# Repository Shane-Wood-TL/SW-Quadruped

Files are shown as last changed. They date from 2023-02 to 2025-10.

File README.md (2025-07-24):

# SW-Quadruped
Quadruped Robot similar to the Boston Dynamic's spot

# Version 9




Uses 12x DS32XX motors controlled by a set of PCA9685s <br>
<t> Planned upgrade to [these servos](https://github.com/Shane-Wood-TL/CAN_Servo/tree/main)<br>
Mircocontroller - ESP32-S3<br>
Gyro: BNO055 - Over CAN bus<br>
[Controller](https://github.com/Shane-Wood-TL/Universal-Robo-Controller)<br>
Lidar over ESP-NOW <br><br>

Power:
20V in from Dewalt battery (20V, 2A), <br>
20V into buck converter (20V - 6.4V),<br>
6.4V Powers servos, <br>
20V into buck converter (20V - 5V), <br>
5V powers ESP32-S3 as well as everything else <br>
I2C is based on 3V3 logic <br>

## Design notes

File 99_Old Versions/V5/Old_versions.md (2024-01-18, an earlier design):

# Version 7
Fixed the body issues of v6 with the use of carbon fiber tubes, similar to v6 otherwise.
PXL_20230803_034527840 PORTRAIT (1)

# Version 6


Similar to V5
The main goal is to reduce tolerance issues within V5 as well as make maintenance easier
Increase mobility range of legs which was reduced in the in/out direction due to the square nature of v5
Switch from a single PCB to 3, 1 main controller board with 2 servo driver boards, which communicate over a custom protocol that consists of I2C and some digital pins
Instead of using wires to connect these boards ethernet wires will be used instead, this is also the main way the controller will have access to other devices, it features 4 ethernet jacks
Given the digital pins that now go to the servo boards, a way to detect if the robot's leg is on the ground is also planned with the help of keyboard switches in the robot's foot

# Version 5
yeet

# Version 4


## Issues
Weak overall body
the way motors are connected to pieces leaves a lot of play
wires being consumed by the design
3d printed bearings not working well for hip joints

# Version 3


## Issues
an awful way for the motor's outputs to be connected

# Version 2


## Issues
Too big for the given motors
Lots of flex in the body
Too large and unstable to do anything

# Version 1


## Issues
Mirco Controller struggling to perform enough trig in a quick manner (could have been a motor issue)
Way too weak of motors (sg90s)
similar issues in stability and body strength as the version that follows

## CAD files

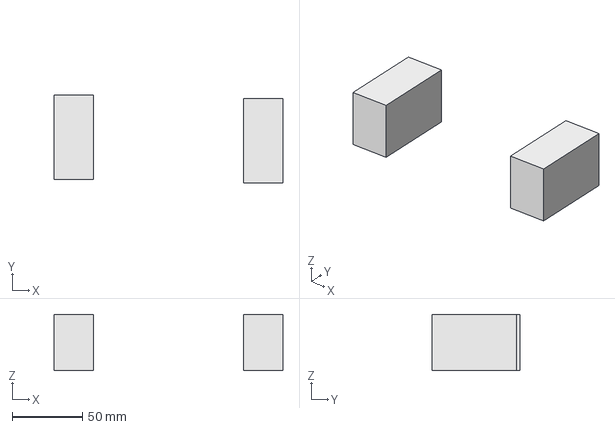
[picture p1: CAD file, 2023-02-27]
CAD/V5/assemblytest2.FCStd
163.3 x 62.5 x 40.3 mm

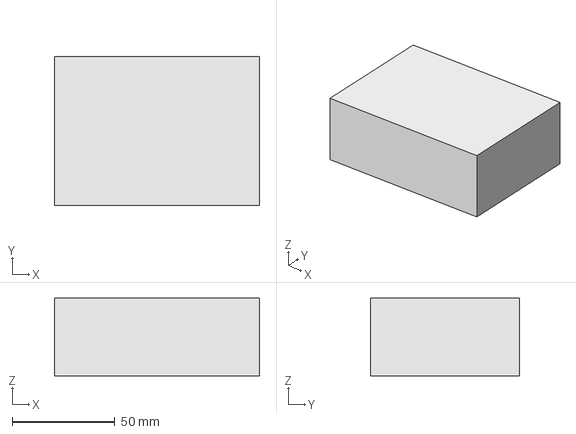
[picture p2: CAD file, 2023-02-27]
CAD/V5/placeholderparts/mainboard.FCStd
100.0 x 72.5 x 38.0 mm

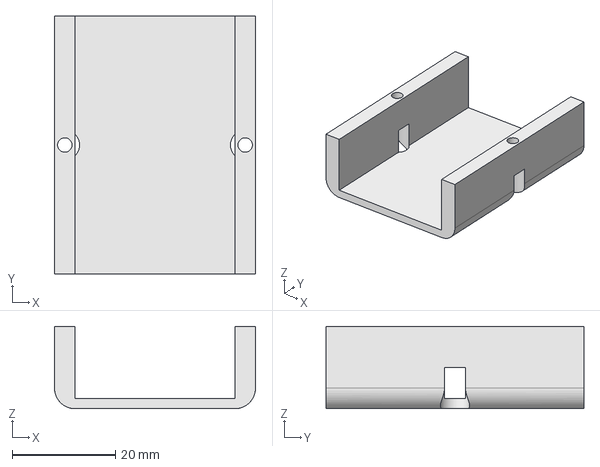
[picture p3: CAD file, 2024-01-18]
01_CAD/small_wire_Holder.FCStd
39.0 x 50.0 x 16.0 mm

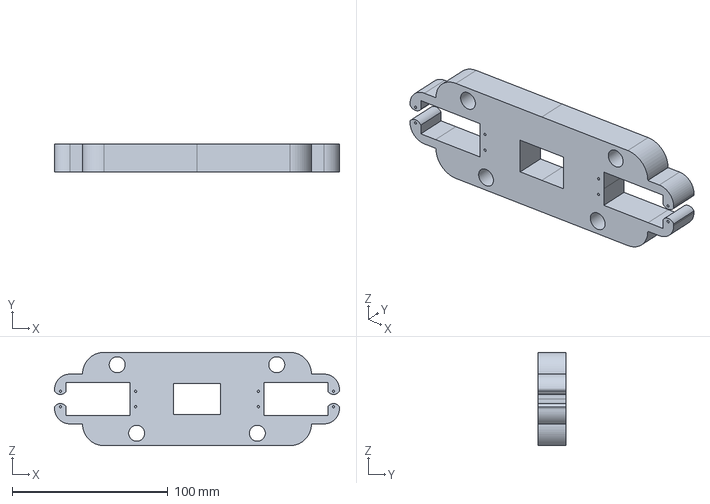
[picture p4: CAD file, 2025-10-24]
01_CAD/V10/Hip/INNER_PLATE.FCStd
183.0 x 18.0 x 60.0 mm

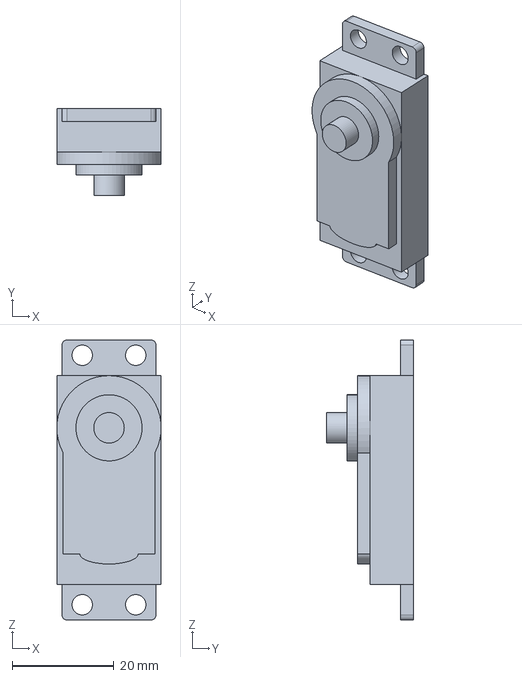
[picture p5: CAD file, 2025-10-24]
01_CAD/V10/Non_Printed_parts/MG996R_TOP.FCStd
20.5 x 17.0 x 55.0 mm

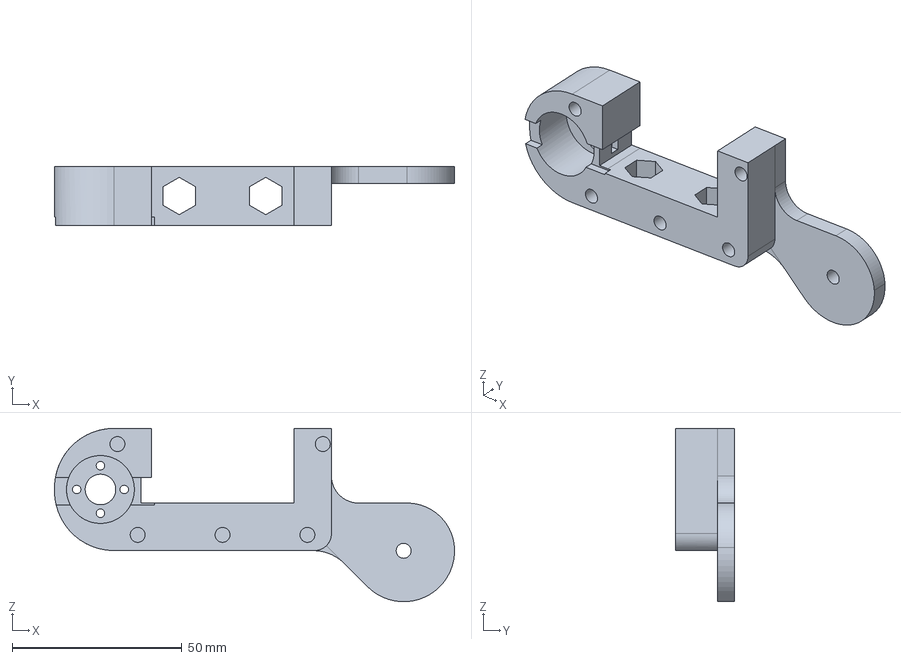
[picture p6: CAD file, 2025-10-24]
01_CAD/V10/Upper_Leg/UPPER_LEG_INNER.FCStd
117.8 x 17.5 x 51.0 mm

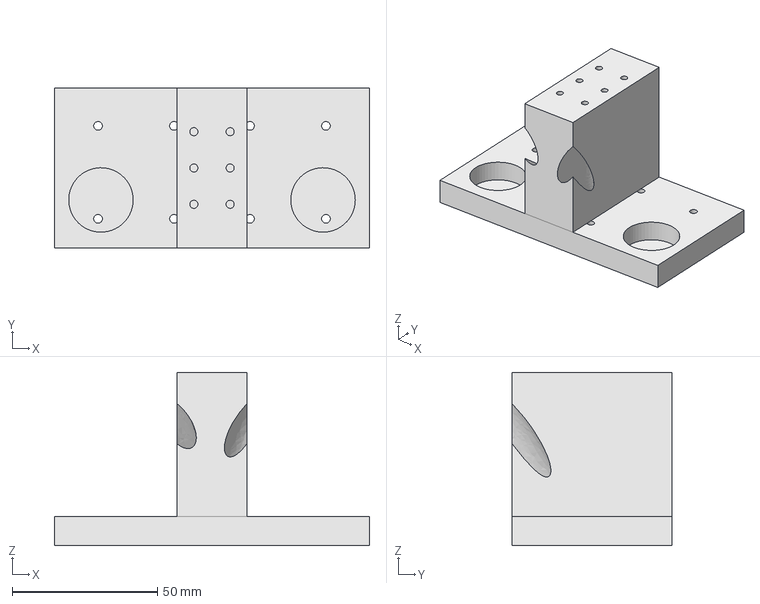
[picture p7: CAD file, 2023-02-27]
CAD/V5/Hip/BackSide/ButtBodyPlate.FCStd
108.5 x 55.0 x 59.8 mm

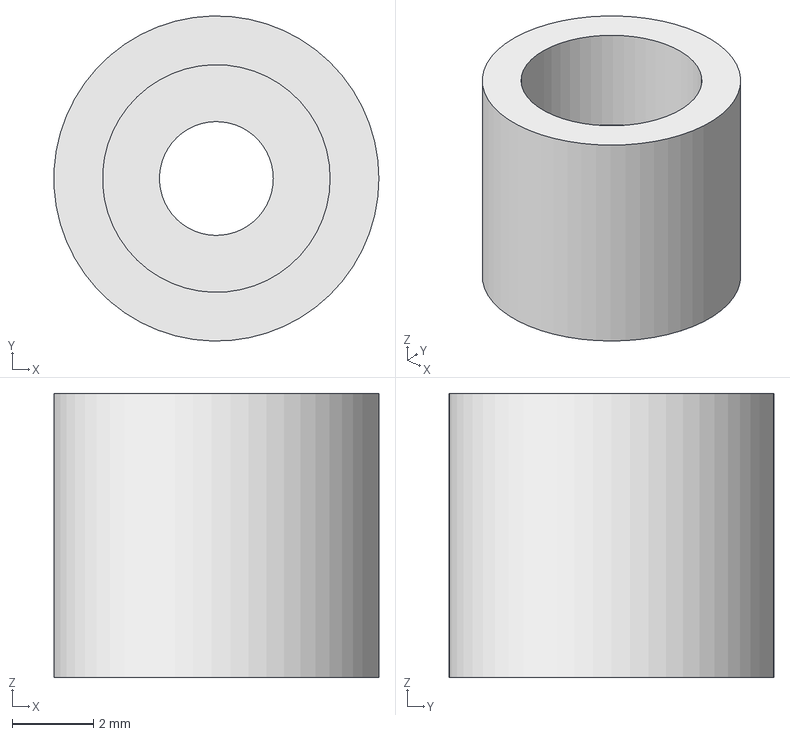
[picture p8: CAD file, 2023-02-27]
CAD/V5/Hip/fixed/bearingShaftFix.FCStd
7.99 x 8.00 x 7.00 mm

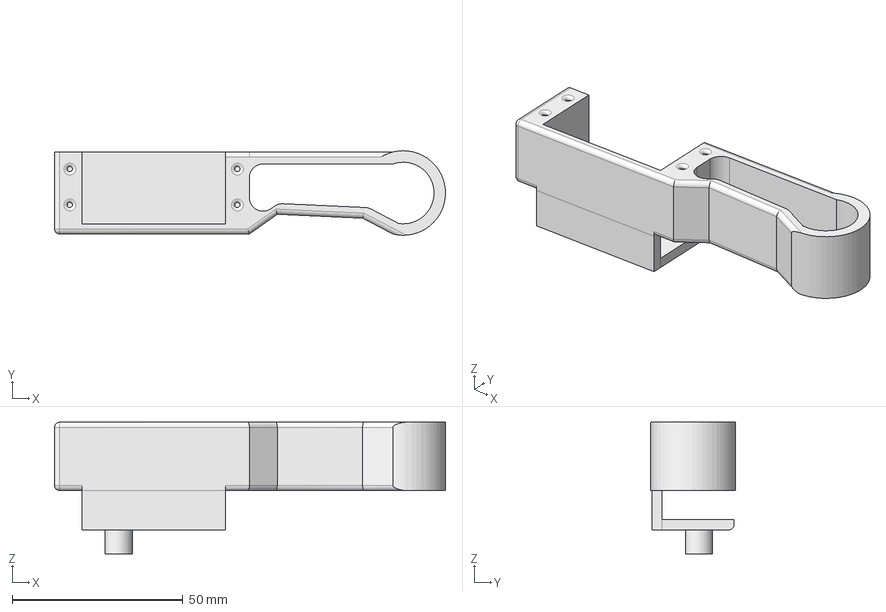
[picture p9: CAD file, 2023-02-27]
CAD/V5/LowerLeg/lowerLeg.FCStd
114.4 x 24.7 x 38.5 mm

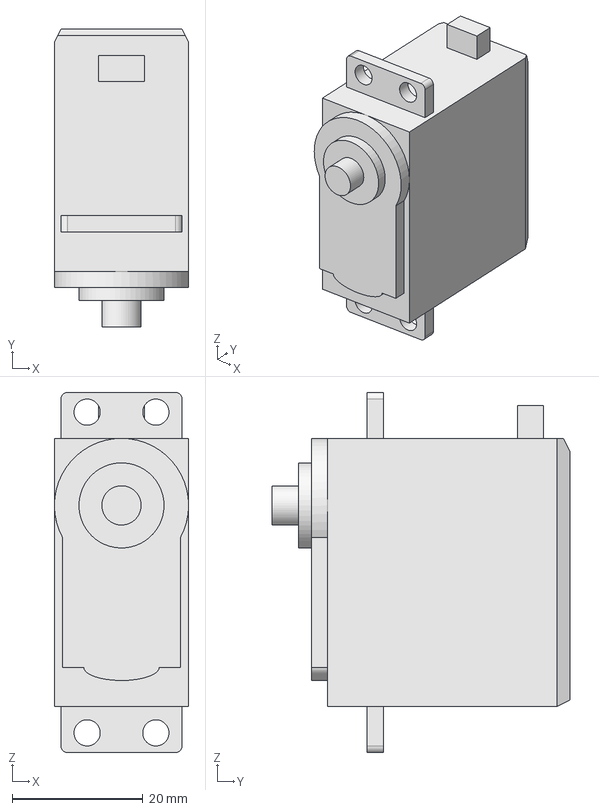
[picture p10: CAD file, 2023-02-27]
CAD/V5/MG996R.FCStd
20.5 x 45.5 x 55.0 mm

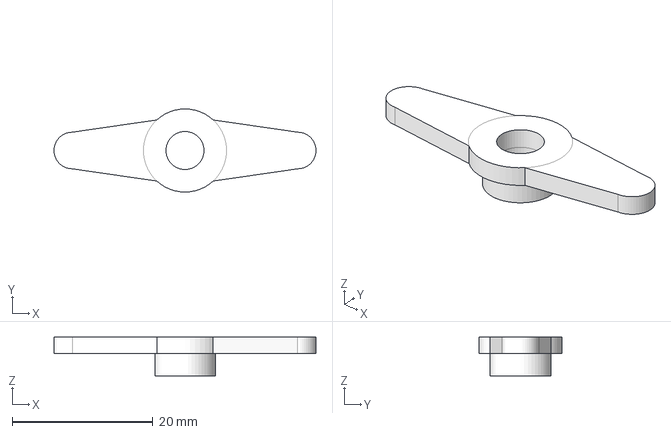
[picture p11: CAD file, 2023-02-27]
CAD/V5/NonPrintedParts/2servohorn.FCStd
37.2 x 11.8 x 5.50 mm

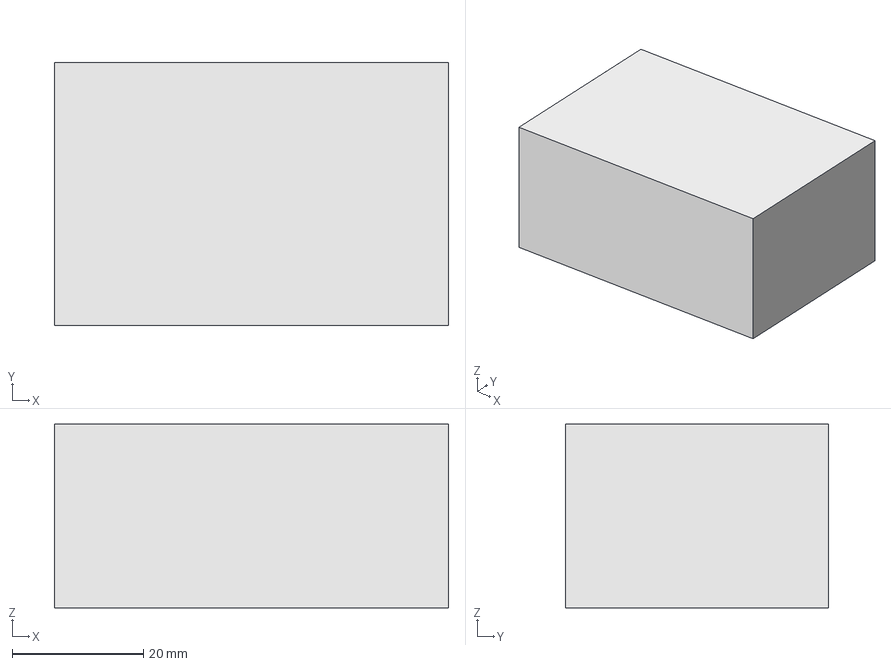
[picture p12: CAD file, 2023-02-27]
CAD/V5/placeholderparts/servoCapBoard.FCStd
60.0 x 40.0 x 28.0 mm

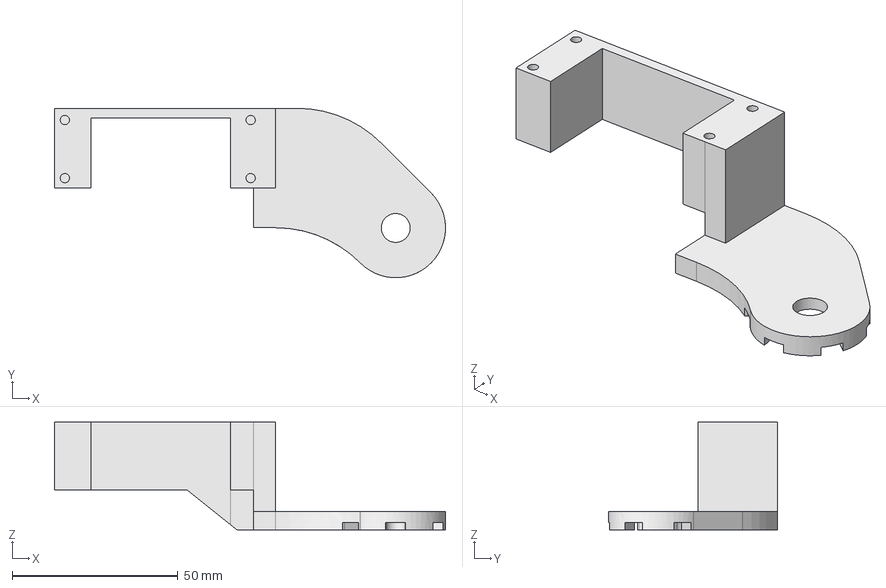
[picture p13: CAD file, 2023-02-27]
CAD/V5/Upper_leg/innerUppler leg.FCStd
117.8 x 51.1 x 32.5 mm

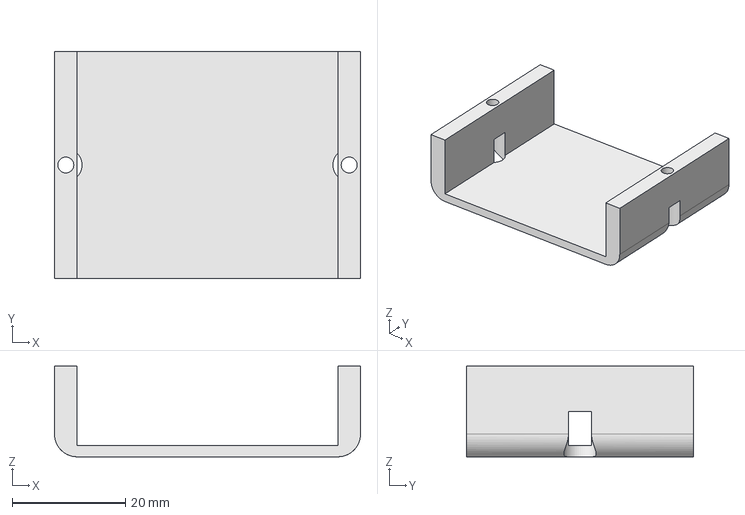
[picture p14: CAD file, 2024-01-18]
01_CAD/large_wire_Holder.FCStd
54.0 x 40.0 x 16.0 mm

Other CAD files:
CAD/V5/Body/bodyassembly.FCStd
01_CAD/V10/V10.FCStd
CAD/V5/Hip/FrontHipPlate.FCStd
01_CAD/V10/Hip/CAN_SERVO_PCB_HOLDER.FCStd
01_CAD/V10/Hip/KNEE_MOTOR_HOLDER.FCStd
01_CAD/V10/Hip/OUTER_PLATE.FCStd
01_CAD/V10/Non_Printed_parts/MG996R.FCStd
01_CAD/V10/Non_Printed_parts/circularServoHorn.FCStd
01_CAD/V10/Upper_Leg/UPPER_LEG_OUTER.FCStd
01_CAD/V7/Body/BatteryHolder.FCStd
01_CAD/V7/Body/Mainboard_Holder.FCStd
01_CAD/V7/Body/ServoDriver.FCStd
01_CAD/V7/Body/Servo_Driver_Holder.FCStd
01_CAD/V7/Body/batteryLid.FCStd
01_CAD/V7/Body/gyro holder.FCStd
01_CAD/V7/Body/lidar_Holder.FCStd
01_CAD/V7/Rod.FCStd
01_CAD/V7/assemv7.FCStd
01_CAD/V7/connecter.FCStd
01_CAD/V7/hip/innerplate.FCStd
01_CAD/V7/hip/plate.FCStd
01_CAD/V7/nonprintables/battery.FCStd
01_CAD/V8/Body/batholder.FCStd
01_CAD/V8/Body/buckandswitch.FCStd
01_CAD/V8/Body/kneeSupport.FCStd
01_CAD/V8/Body/lowandbuck.FCStd
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

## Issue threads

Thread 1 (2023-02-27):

Oscillation when robot attempts to fully level

Townlake101, 2023-02-27:
Needs some form of pid loop to establish a way to prevent the robot from changing its height too much during 1 move, especially if it is still essentially level.

Townlake101, 2023-04-18:
Also resolved with a PID loop + adding limits to the kinematic model to prevent motor damage

Closed 2023-04-18.

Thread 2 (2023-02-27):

Walking gate has not been tested with new gyro

Townlake101, 2023-02-27:

Townlake101, 2023-04-18:
PID added on gyro, oscillation is no longer present

Closed 2023-04-18.

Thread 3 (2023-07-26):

Motors do not move properly when xFB is positive (leg moving forward past the hip axis)

Townlake101, 2023-07-26:
Due to the different way that the kinematic model is calculated for this situation was well as some of the motors changing directions in between v5 to present this part of the code needs to be reworked

Townlake101, 2023-08-02:
Code for xFB (leg moving forward / backward) is working for backward movement and will base forward code upon the current design

Townlake101, 2023-08-11:
This issue has been resolved by adding a rule to handle positive xFB values differently in the kinematic model

Closed 2023-08-11.

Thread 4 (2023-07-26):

New cad needs to be uploaded

Shane-Wood-TL, 2023-07-26:
Cad in repository is currently based on v5

Townlake101, 2023-07-26:
Cad has been uploaded and moved, live files are still missing the leg model

Shane-Wood-TL, 2024-01-18:
V8 has been uploaded

Closed 2024-01-18.

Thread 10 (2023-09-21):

Robot Controller CAD + wiring diagram

Shane-Wood-TL, 2023-09-21:
CAD for robot controller needs to be added to the repository as well as how it is wired

Shane-Wood-TL, 2023-11-03:
PCB was made, so no wiring diagram, new cad does not exist yet, but it will be added once it is made

Shane-Wood-TL, 2024-01-18:
Added Under new repository, can be found here
https://github.com/Shane-Wood-TL/Universal-Robo-Controller

Closed 2024-01-18.

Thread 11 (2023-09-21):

Power for robot is unsatisfactory, at best

Shane-Wood-TL, 2023-09-21:
The current design of the bot uses a 65-watt USB C power bank and a USB PD breakout board to deliver 65W at 20V to the main buck converter. While this works it is far from ideal. The powerbank is heavy, a majority of the weight of the bot itself which is putting more strain on the motors. The USB PD board is not acceptable considering the amount of heat it outputs, leading to more energy loss.

Townlake101, 2023-09-21:
There is currently a plan to switch over to some form of power tool battery to stop using the USB PD board as it gets far hotter than a component in spec should. This switch would also add a fuse leading to some actual safety measures in the bot.

However, this switch is going to be costly so it will not happen until the limits of the 65W battery have been reached.

Shane-Wood-TL, 2023-11-03:
Battery conversion has been completed, BOM needs to be updated

Closed 2023-11-03.

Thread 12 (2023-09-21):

Using a SD card to save values

Townlake101, 2023-09-21:
Rather than having things like motor offsets hard-coded into the files allowing the user to set them via the controller and save them internally onto the robot would allow for a better user experience and might make the creation of custom moves easier

Shane-Wood-TL, 2023-11-03:
Rather than add a sd card, having some way to show the offset on the controller and then being able to add them in code is likely a better way to resolve this issue

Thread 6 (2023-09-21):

Ethernet is too bulky in design

Townlake101, 2023-09-21:
The ethernet jacks on the main controller make it impossible to use all 4 jacks as it will hit the gyro holder. Switching to a low profile connecter would resolve this

Townlake101, 2023-09-21:
New PCB version (not pushed yet) switches to generic 2x5 2.54 breadboard headers witch should resolve this issue

Shane-Wood-TL, 2023-11-03:
This had been fully resolved and tested with the current pcb

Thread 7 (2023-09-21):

Mainboard Issues

Shane-Wood-TL, 2023-09-21:
The mainboard is missing a good 3V3 volt source (taking power from ESP32 is not advisable) Next PCB should have a 3v3 volt regulator. Along with this, the I2C bus needs to be fully converted to 3V3 as the PCA9685's are still currently on a 5V setup which could damage the ESP32.

Along with this, a spot for the NRF2401 should be added to the PCB since it is the radio that is used.

Townlake101, 2023-09-21:
The new PCB version (not pushed yet) has a 3v3 regulator on board and a spot for the NRF2401 with a capacitor in place. It also switches the PCA9685s to 3v3

Shane-Wood-TL, 2023-11-03:
This issue has been fully resolved with the current pcb

Closed 2023-11-03.

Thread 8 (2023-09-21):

User control does not work as expected

Shane-Wood-TL, 2023-09-21:
Unsure of why this is, motors either do not move at all or they are moving in the wrong direction. Debugging this will take a bit, however, user control is vital to having non-human control in the future.

Shane-Wood-TL, 2024-01-18:
User control works as expected, it needs further tweaking, but it is functional

Closed 2024-01-18.

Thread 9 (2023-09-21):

Gyro + Controller

Townlake101, 2023-09-21:
Gyro does not appear to work with the controller even if enabled. Suspecting it is a issue with the PID controller as it might be getting to far away from 0 leading to unexpected results

Shane-Wood-TL, 2023-11-03:
Pid is still currently broken as well as writing angles to the legs when walking. The gyro is implemented properly in terms of the base kinematic model

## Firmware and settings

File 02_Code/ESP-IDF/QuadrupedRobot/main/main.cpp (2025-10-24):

#include "../include/hardware_setup/pinout.h"
#include "../include/hardware_setup/i2c_setup.h"
#include "../include/hardware_setup/motor_offsets.h"
#include "../include/wireless_setup/structures.h"
#include "../include/all_includes.h"
#include "../include/motion_system/structures.h"
#include "../include/motion_system/kinematics.h"
#include "../include/motion_system/ramp_leg.h"
#include "../include/motion_system/ramped_kinematics.h"
#include "../include/motion_system/robot_movement.h"

#include "../include/drivers/bno055.h"

#include <nvs_flash.h>
#include "espnow_ctrl.h"
#include "espnow_utils.h"

#include "led_strip.h"

#include "driver/adc.h"
//#include "driver/i2c_master.h"
void servo_driver(void *pv);
void send_data_task(void *pv);
void led_driver(void *pv);
void current_voltage_measurements_task(void *pv);
void gyroscope_task(void *pv);

void start_esp_now();
void start_I2C();
void start_TWAI();

static uint8_t robotMacAddress[6] = {0x34, 0x85, 0x18, 0xA5, 0x74, 0x48};
static uint8_t controller_mac_address[6] = {0x68,0xB6,0xB3,0x52,0xB1,0xAC};

controller_to_bot_payload controller_to_bot = {0};


enum mode_options_enum{STAND, IK, WALK, TURN, USER, MOTORSET};


SemaphoreHandle_t mode_mutex;
uint8_t mode =0;

SemaphoreHandle_t settings_mutex;
bool pid =false;
bool gyro = false;
bool motors_disabled = true;

SemaphoreHandle_t joystick_0_x_mutex;
int8_t joystick_0_x=0;

SemaphoreHandle_t joystick_0_y_mutex;
int8_t joystick_0_y=0;

SemaphoreHandle_t joystick_1_x_mutex;
int8_t joystick_1_x=0;

SemaphoreHandle_t joystick_1_y_mutex;
int8_t joystick_1_y=0;

SemaphoreHandle_t battery_voltage_mutex;
float battery_voltage=0;

SemaphoreHandle_t battery_current_mutex;
float battery_current=0;

SemaphoreHandle_t motor_current_mutex;
float motor_current=0;


SemaphoreHandle_t led_status_mutex;
bool led_status = false;




//i2c bus config
//i2c_master_bus_config_t i2c_mst_config;

//i2c_master_bus_handle_t bus_handle;


SemaphoreHandle_t gyro_angles_mutex;
float gyro_angles[3] = {0};


// Updated callback function to handle received data
void on_receive(const esp_now_recv_info_t *recv_info, const uint8_t *data, int len) {
    //printf("received\n");
    // printf("Received from MAC: %02X:%02X:%02X:%02X:%02X:%02X\n",
    //        recv_info->src_addr[0], recv_info->src_addr[1], recv_info->src_addr[2],
    //        recv_info->src_addr[3], recv_info->src_addr[4], recv_info->src_addr[5]);

    controller_to_bot_payload received_data;
    if (len == sizeof(received_data)) {
        memcpy(&received_data, data, sizeof(received_data));
        if(xSemaphoreTake(settings_mutex,portMAX_DELAY)){
            pid = ((received_data.settings >> 5) & 1);
            gyro = ((received_data.settings >> 6) & 1);
            motors_disabled = ((received_data.settings >> 7) & 1);
            xSemaphoreGive(settings_mutex);
        }
        if(xSemaphoreTake(mode_mutex,portMAX_DELAY)){
            mode = received_data.mode;
            xSemaphoreGive(mode_mutex);
        }
        if(xSemaphoreTake(led_status_mutex,portMAX_DELAY)){
            led_status = ((received_data.settings >> 4) & 1);
            xSemaphoreGive(led_status_mutex);
        }
    }else{
        printf("Unexpected data length: %d\n", len);
    }
}


void on_send(const uint8_t *mac_addr, esp_now_send_status_t status) {
    static bool last_transmit_state=false;
    // printf("Send to MAC: %02X:%02X:%02X:%02X:%02X:%02X, Status: %s\n",
    //        mac_addr[0], mac_addr[1], mac_addr[2], mac_addr[3], mac_addr[4], mac_addr[5],
    //        (status == ESP_NOW_SEND_SUCCESS) ? "Success" : "Fail");
    if(status == ESP_NOW_SEND_SUCCESS){
            
    }else{
        
    }
    return;
}



//task that sends controller data
void send_data_task(void *pvParameter) {
   
    while (1) {
        float last_battery_voltage = 0;
        float last_battery_current = 0;
        float last_motor_current = 0;
        if(xSemaphoreTake(battery_voltage_mutex, portMAX_DELAY)){
            last_battery_voltage = battery_voltage;
            xSemaphoreGive(battery_voltage_mutex);
        }
        
        if(xSemaphoreTake(battery_current_mutex, portMAX_DELAY)){
            last_battery_current = battery_current;
            xSemaphoreGive(battery_current_mutex);
        }

        if(xSemaphoreTake(motor_current_mutex, portMAX_DELAY)){
            last_motor_current = motor_current;
            xSemaphoreGive(motor_current_mutex);
        }
        bot_to_controller_payload current_transmission = {last_battery_voltage,last_battery_current,last_motor_current};
        esp_err_t transmit_error = esp_now_send(controller_mac_address, (uint8_t *)&current_transmission, sizeof(bot_to_controller_payload));
        vTaskDelay(pdMS_TO_TICKS(1000));
    }
}



void start_esp_now(){
    // Initialize NVS
    esp_err_t ret = nvs_flash_init();
    if (ret == ESP_ERR_NVS_NO_FREE_PAGES || ret == ESP_ERR_NVS_NEW_VERSION_FOUND) {
        ESP_ERROR_CHECK(nvs_flash_erase());
        ret = nvs_flash_init();
    }
    ESP_ERROR_CHECK(ret);

    // Initialize Wi-Fi in STA mode
    ESP_ERROR_CHECK(esp_netif_init());
    ESP_ERROR_CHECK(esp_event_loop_create_default());
    wifi_init_config_t cfg = WIFI_INIT_CONFIG_DEFAULT();
    ESP_ERROR_CHECK(esp_wifi_init(&cfg));
    ESP_ERROR_CHECK(esp_wifi_set_mode(WIFI_MODE_STA));
    ESP_ERROR_CHECK(esp_wifi_start());

    // Initialize ESP-NOW
    ESP_ERROR_CHECK(esp_now_init());
    esp_now_register_recv_cb(on_receive);
    esp_now_register_send_cb(on_send);

    esp_now_peer_info_t peer_info = {};
    memcpy(peer_info.peer_addr, controller_mac_address, 6);
    peer_info.channel = 0;
    peer_info.encrypt = false;
    ESP_ERROR_CHECK(esp_now_add_peer(&peer_info));
}


extern "C" void app_main(void)
{
    mode_mutex = xSemaphoreCreateMutex();
    settings_mutex = xSemaphoreCreateMutex();
    joystick_0_x_mutex = xSemaphoreCreateMutex();
    joystick_0_y_mutex = xSemaphoreCreateMutex();
    joystick_1_x_mutex = xSemaphoreCreateMutex();
    joystick_1_y_mutex = xSemaphoreCreateMutex();
    battery_voltage_mutex = xSemaphoreCreateMutex();
    battery_current_mutex = xSemaphoreCreateMutex();
    motor_current_mutex = xSemaphoreCreateMutex();
    led_status_mutex = xSemaphoreCreateMutex();
    gyro_angles_mutex = xSemaphoreCreateMutex();
    start_I2C();
    start_esp_now();
    //start_TWAI();

    xTaskCreate(servo_driver,"servo_driver",4096,NULL,1,NULL);
    xTaskCreate(led_driver,"led_driver",20000,NULL,3,NULL);
    xTaskCreate(send_data_task,"send_data",4096,NULL,4,NULL);
    xTaskCreate(current_voltage_measurements_task, "current_voltage", 4096, NULL, 2, NULL);
    //xTaskCreate(gyroscope_task, "gyroscope_task", 8096, NULL, 2, NULL);
    for(;;){
        vTaskDelay(pdMS_TO_TICKS(10000));
    }
}




void led_driver(void *pv){
        /// LED strip common configuration
    led_strip_config_t led_strip_front_config = {
        .strip_gpio_num = led_strip_front,  // The GPIO that connected to the LED strip's data line
        .max_leds = 8,                 // The number of LEDs in the strip,
        .led_model = LED_MODEL_WS2812, // LED strip model, it determines the bit timing
        .color_component_format = LED_STRIP_COLOR_COMPONENT_FMT_GRB, // The color component format is G-R-B
        .flags = {
            .invert_out = false, // don't invert the output signal
        }
    };

    /// RMT backend specific configuration
    led_strip_rmt_config_t rmt_config = {
        .clk_src = RMT_CLK_SRC_DEFAULT,    // different clock source can lead to different power consumption
        .resolution_hz = 10 * 1000 * 1000, // RMT counter clock frequency: 10MHz
        .mem_block_symbols = 64,           // the memory size of each RMT channel, in words (4 bytes)
        .flags = {
            .with_dma = false, // DMA feature is available on chips like ESP32-S3/P4
        }
    };

    /// Create the LED strip object
    led_strip_handle_t led_strip_front_handle;
    ESP_ERROR_CHECK(led_strip_new_rmt_device(&led_strip_front_config, &rmt_config, &led_strip_front_handle));

    /// LED strip common configuration
    led_strip_config_t led_strip_back_config = {
        .strip_gpio_num = led_strip_back,  // The GPIO that connected to the LED strip's data line
        .max_leds = 8,                 // The number of LEDs in the strip,
        .led_model = LED_MODEL_WS2812, // LED strip model, it determines the bit timing
        .color_component_format = LED_STRIP_COLOR_COMPONENT_FMT_GRB, // The color component format is G-R-B
        .flags = {
            .invert_out = false, // don't invert the output signal
        }
    };

    /// Create the LED strip object
    led_strip_handle_t led_strip_back_handle;
    ESP_ERROR_CHECK(led_strip_new_rmt_device(&led_strip_back_config, &rmt_config, &led_strip_back_handle));

    for(uint8_t i =0; i < 8; i++){
        led_strip_set_pixel(led_strip_front_handle, i, 0, 0, 255);
        led_strip_set_pixel(led_strip_back_handle, i, 0, 0, 255);
    }

    led_strip_refresh(led_strip_front_handle);
    led_strip_refresh(led_strip_back_handle);

    static bool last_led_status = true;
    for(;;){
        bool update = false;
        if(xSemaphoreTake(led_status_mutex, portMAX_DELAY)){
            if(last_led_status != led_status){
                update = true;
                last_led_status = led_status;
            }
            xSemaphoreGive(led_status_mutex);
        }
        if(update){
            if(led_status){
                for(uint8_t i =0; i < 8; i++){
                    led_strip_set_pixel(led_strip_front_handle, i, 0, 0, 255);
                    led_strip_set_pixel(led_strip_back_handle, i, 0, 0, 255);
                }
            }else{
                for(uint8_t i =0; i < 8; i++){
                    led_strip_set_pixel(led_strip_front_handle, i, 0, 0, 0);
                    led_strip_set_pixel(led_strip_back_handle, i, 0, 0, 0);
                }
            }
            led_strip_refresh(led_strip_front_handle);
            led_strip_refresh(led_strip_back_handle);
        }
        vTaskDelay(pdMS_TO_TICKS(1000));
    }
}


void current_voltage_measurements_task(void *pv){
    //#define current_sense_pin GPIO_NUM_13 ADC2_2
    //#define voltage_sense_pin GPIO_NUM_14 ADC2_3
    int raw_voltage_reading = 0;
    int raw_current_reading = 0; //26.4 mV/A 0-4095
    
    for(;;){
        adc2_get_raw(ADC2_CHANNEL_2, ADC_WIDTH_BIT_12, &raw_current_reading);
        adc2_get_raw(ADC2_CHANNEL_3, ADC_WIDTH_BIT_12, &raw_voltage_reading);

        if(xSemaphoreTake(battery_voltage_mutex, portMAX_DELAY)){
            battery_voltage = (raw_voltage_reading/136.0f)-2.35f;
            xSemaphoreGive(battery_voltage_mutex);
        }



        if(xSemaphoreTake(battery_current_mutex, portMAX_DELAY)){
            //2015 = measured 0 point 
            //32.76 = given 26.4 mV/A / (3.3/4095)
            battery_current = (raw_current_reading-2015)/32.76f;
            xSemaphoreGive(battery_current_mutex);
        }

        if(xSemaphoreTake(motor_current_mutex, portMAX_DELAY)){
            motor_current = 0;
            xSemaphoreGive(motor_current_mutex);
        }
        vTaskDelay(pdMS_TO_TICKS(10));
    }
}



void servo_driver(void *pv){
    position aCords;
    position bCords;
    position cCords;
    position dCords;

    all_motor_angles activeOffsets={(float)A_HIP_OFFSET,(float)A_KNEE_OFFSET,(float)A_ANKLE_OFFSET,
                            (float)B_HIP_OFFSET,(float)B_KNEE_OFFSET,(float)B_ANKLE_OFFSET,
                            (float)C_HIP_OFFSET,(float)C_KNEE_OFFSET,(float)C_ANKLE_OFFSET,
                            (float)D_HIP_OFFSET,(float)D_KNEE_OFFSET,(float)D_ANKLE_OFFSET};

    pca9685 driver0((uint8_t)pca9685_address_0);
    pca9685 driver1((uint8_t)pca9685_address_1);
    // motor(pca9685* pwmV, uint8_t motorV, uint16_t LlimitV, uint16_t HlimitV, bool directionV, float* offsetV);
    motor aHipM(&driver0, (uint8_t)aHip, 45, 135, true, &(activeOffsets.A_hip));
    motor aKneeM(&driver0, (uint8_t)aKnee, 0, 180, false, &(activeOffsets.A_knee));
    motor aAnkleM(&driver0, (uint8_t)aAnkle, 0, 180, true, &(activeOffsets.A_ankle));

    motor bHipM(&driver0, bHip, 45, 135, false, &(activeOffsets.B_hip));
    motor bKneeM(&driver0, bKnee, 0, 180, true, &(activeOffsets.B_knee));
    motor bAnkleM(&driver0, bAnkle, 0, 180, false, &(activeOffsets.B_ankle));

    motor cHipM(&driver1, cHip, 45, 135, false, &(activeOffsets.C_hip));
    motor cKneeM(&driver1, cKnee, 0, 180, false, &(activeOffsets.C_knee));
    motor cAnkleM(&driver1, cAnkle, 0, 180, true, &(activeOffsets.C_ankle));

    motor dHipM(&driver1, dHip, 45, 135, true, &(activeOffsets.D_hip));
    motor dKneeM(&driver1, dKnee, 0, 180, true, &(activeOffsets.D_knee));
    motor dAnkleM(&driver1, dAnkle, 0, 180, false, &(activeOffsets.D_ankle));

    leg Aleg(&aHipM, &aKneeM, &aAnkleM, 'A');
    leg Bleg(&bHipM, &bKneeM, &bAnkleM, 'B');
    leg Cleg(&cHipM, &cKneeM, &cAnkleM, 'C');
    leg Dleg(&dHipM, &dKneeM, &dAnkleM, 'D');

    kinematics AlegK(&Aleg);
    kinematics BlegK(&Bleg);
    kinematics ClegK(&Cleg);
    kinematics DlegK(&Dleg);

    rampLeg aLegR(aHip);
    rampLeg bLegR(bHip);
    rampLeg cLegR(cHip);
    rampLeg dLegR(dHip);

    //ramped_kinematics(kinematics *kinematic_driver, rampLeg *ramped_driver);
    vTaskDelay(pdMS_TO_TICKS(100));    
    ramped_kinematics a_leg_rk(&AlegK,&aLegR);
    ramped_kinematics b_leg_rk(&BlegK,&bLegR);
    ramped_kinematics c_leg_rk(&ClegK,&cLegR);
    ramped_kinematics d_leg_rk(&DlegK,&dLegR);

    position basicStand;


    basicStand.z = 130;
    basicStand.x = 0;
    basicStand.y = 0;
    
    a_leg_rk.set_stance(basicStand);
    b_leg_rk.set_stance(basicStand);
    c_leg_rk.set_stance(basicStand);
    d_leg_rk.set_stance(basicStand);

    float cycleTime = 20;
    float moveBackDistance = -50;
    float moveUpDistance =-30;

    //float xH float xFB float xLR float rot_x float rot_y float rot_z
    static position walk_position_0(basicStand.z,0,0,0,0,0);
    static position walk_position_1(basicStand.z,moveBackDistance/3,0,0,0,0);
    static position walk_position_2(basicStand.z,2*moveBackDistance/3,0,0,0,0);
    static position walk_position_3(basicStand.z+moveUpDistance,moveBackDistance,0,0,0,0);
    static position walk_position_4(basicStand.z+moveUpDistance,2*moveBackDistance/3,0,0,0,0);
    static position walk_position_5(basicStand.z+moveUpDistance,moveBackDistance/3,0,0,0,0);

    
    float stance_time = 0.2f;
    static stance walk0(&walk_position_0,&walk_position_3,&walk_position_3,&walk_position_0,stance_time);
    static stance walk1(&walk_position_1,&walk_position_4,&walk_position_4,&walk_position_1,stance_time);
    static stance walk2(&walk_position_2,&walk_position_5,&walk_position_5,&walk_position_2,stance_time);
    static stance walk3(&walk_position_3,&walk_position_0,&walk_position_0,&walk_position_3,stance_time);
    static stance walk4(&walk_position_4,&walk_position_1,&walk_position_1,&walk_position_4,stance_time);
    static stance walk5(&walk_position_5,&walk_position_2,&walk_position_2,&walk_position_5,stance_time);
    static stance *walk_forward_stances[6] = {&walk0,&walk1,&walk2,&walk3,&walk4,&walk5};
    vTaskDelay(pdMS_TO_TICKS(100));    
    
    //cycle(uint8_t cycle_length, stance **stances, bool direction);
    static cycle walk_forward(6,walk_forward_stances,true);

    static robot_movement robot_movement_test(&a_leg_rk,&b_leg_rk,&c_leg_rk,&d_leg_rk, &walk_forward);
    for(;;){
        float yAngle = 0;
        float xAngle = 0;
        float zAngle = 0;
        float xAngleV = 0;
        float yAngleV = 0;
        static uint8_t current_mode= 0;

        if(xSemaphoreTake(mode_mutex,portMAX_DELAY)){
            current_mode = mode;
            xSemaphoreGive(mode_mutex);
        }

        if(xSemaphoreTake(settings_mutex,portMAX_DELAY)){
            if(!motors_disabled){
                xSemaphoreGive(settings_mutex);
                //driver0.wake();
                //driver1.wake();
                printf("a\n");
                switch(current_mode){
                    //STAND, IK, WALK, TURN, USER, MOTORSET};
                    case(STAND):{
                        printf("b\n");
                        a_leg_rk.set_stance(basicStand);
                        b_leg_rk.set_stance(basicStand);
                        c_leg_rk.set_stance(basicStand);
                        d_leg_rk.set_stance(basicStand);
                        break;
                    }
                    case(IK):
                    printf("c\n");
                        break;
                    case(WALK):{
                        printf("d\n");
                        robot_movement_test.update();
                        break;
                    }
                    case(TURN):
                        break;
                    case(USER):
                        break;
                    case(MOTORSET):{
                        break;
                    }
                }

            }else{
                driver0.sleep();
                driver1.sleep();
                xSemaphoreGive(settings_mutex);
            }
            
        }
        vTaskDelay(pdMS_TO_TICKS(20));    

    }
}


void start_I2C(){
    // i2c_mst_config.clk_source = I2C_CLK_SRC_DEFAULT;
    // i2c_mst_config.i2c_port = I2C_NUM_0;
    // i2c_mst_config.sda_io_num = sda_pin;
    // i2c_mst_config.scl_io_num = scl_pin;
    // i2c_mst_config.glitch_ignore_cnt = 0;
    // i2c_mst_config.flags.enable_internal_pullup = true;
    // ESP_ERROR_CHECK(i2c_new_master_bus(&i2c_mst_config, &bus_handle));



    i2c_config_t conf = {};
        conf.mode = I2C_MODE_MASTER; //esp32s2 will be master
        conf.master.clk_speed = 400000; //clock speed for i2c
        conf.scl_io_num = scl_pin; //scl pin
        conf.sda_io_num = sda_pin; //sda pin  
        //.scl_pullup_en = GPIO_PULLUP_ENABLE,
        //.sda_pullup_en = GPIO_PULLUP_ENABLE
    //map the config to the i2c number
    i2c_param_config(I2C_NUM_0, &conf);
    i2c_driver_install(I2C_NUM_0, conf.mode, 0, 0, 0);
}


void gyroscope_task(void *pv){
    bno055 gyro(30); //30

    for(;;){
        gyro.get_angles();
        //printf("alive\n");
        vTaskDelay(pdMS_TO_TICKS(10));
    }




}

void start_TWAI(){
    static const twai_timing_config_t t_config = TWAI_TIMING_CONFIG_100KBITS();
    static const twai_filter_config_t f_config = TWAI_FILTER_CONFIG_ACCEPT_ALL();
    
    static const twai_general_config_t g_config = {
        .controller_id = 0,
        .mode = TWAI_MODE_NORMAL,
        .tx_io = c2_6_pin,
        .rx_io = c2_5_pin,
        .clkout_io = TWAI_IO_UNUSED,
        .bus_off_io = TWAI_IO_UNUSED,
        .tx_queue_len = 1,
        .rx_queue_len = 1,
        .alerts_enabled = TWAI_ALERT_NONE,
        .clkout_divider = 0,
        .intr_flags = 0
    };

    if (twai_driver_install(&g_config, &t_config, &f_config) != ESP_OK)
    {
        assert(false);
    }

    while (twai_start() != ESP_OK)
    {
        assert(false);
    }
}





































// void start_TWAI(){
//     static const twai_timing_config_t timing_config = TWAI_TIMING_CONFIG_50KBITS();
//     static const twai_filter_config_t filter_config = TWAI_FILTER_CONFIG_ACCEPT_ALL();
//     static const twai_general_config_t general_config = {
//         .mode = TWAI_MODE_NORMAL,
//         .tx_io = can_TX_pin,
//         .rx_io = can_RX_pin,
//         .clkout_io = TWAI_IO_UNUSED,
//         .bus_off_io = TWAI_IO_UNUSED,
//         .tx_queue_len = 1,
//         .rx_queue_len = 1,
//         .alerts_enabled = TWAI_ALERT_NONE,
//         .clkout_divider = 0
//     };
  
//     if (twai_driver_install(&general_config, &timing_config, &filter_config) == ESP_OK) {
//         ESP_LOGI("can", "TWAI driver installed");
//     } else {
//         ESP_LOGE("can", "Failed to install TWAI driver");
//     }

//     if (twai_start() != ESP_OK) {
//         ESP_LOGI("can", "Failed to start TWAI driver");
//         vTaskDelay(pdMS_TO_TICKS(1000));
//         esp_restart();
//     }
// }

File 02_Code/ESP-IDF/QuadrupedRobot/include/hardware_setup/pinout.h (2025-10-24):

#ifndef __pinout__
#define __pinout__

#include "../all_includes.h"


#define usbDataMinus GPIO_NUM_19
#define usbDataPlus GPIO_NUM_20

#define sda_pin GPIO_NUM_4
#define scl_pin GPIO_NUM_5

#define c0_5_pin GPIO_NUM_6
#define c0_6_pin GPIO_NUM_7
#define c0_7_pin GPIO_NUM_15
#define c0_8_pin GPIO_NUM_16
#define c0_9_pin GPIO_NUM_17

#define c1_5_pin GPIO_NUM_18
#define c1_6_pin GPIO_NUM_8
#define c1_7_pin GPIO_NUM_9
#define c1_8_pin GPIO_NUM_10
#define c1_9_pin GPIO_NUM_11

#define current_sense_pin GPIO_NUM_13
#define voltage_sense_pin GPIO_NUM_14

#define c2_5_pin GPIO_NUM_1
#define c2_6_pin GPIO_NUM_2
#define c2_7_pin GPIO_NUM_42
#define c2_8_pin GPIO_NUM_41
#define c2_9_pin GPIO_NUM_40

#define c3_5_pin GPIO_NUM_39
#define c3_6_pin GPIO_NUM_38
#define c3_7_pin GPIO_NUM_37
#define c3_8_pin GPIO_NUM_36
#define c3_9_pin GPIO_NUM_35

#define can_TX_pin GPIO_NUM_48
#define can_RX_pin GPIO_NUM_47


#define led_strip_front c0_6_pin
#define led_strip_back c3_6_pin


#endif



/*Controller
#define x0_pin GPIO_NUM_4
#define y0_pin GPIO_NUM_5
#define z0_pin GPIO_NUM_6

#define x1_pin GPIO_NUM_7
#define y1_pin GPIO_NUM_15
#define z1_pin GPIO_NUM_16

#define btn_0 GPIO_NUM_17
#define btn_1 GPIO_NUM_18

#define swA_0 GPIO_NUM_8
#define swA_1 GPIO_NUM_9

#define swB_0 GPIO_NUM_10
#define swB_1 GPIO_NUM_38

#define swC_0 GPIO_NUM_37
#define swC_1 GPIO_NUM_36

#define swD_0 GPIO_NUM_35
#define swD_1 GPIO_NUM_48

#define swE_0 GPIO_NUM_47
#define swE_1 GPIO_NUM_21

#define mosi_pin GPIO_NUM_11
#define sclk_pin GPIO_NUM_13
#define dataCommand_pin GPIO_NUM_14

#define d0_CS GPIO_NUM_1
#define d0_RS GPIO_NUM_41

#define d1_CS GPIO_NUM_2
#define d1_RS GPIO_NUM_40

#define d2_CS GPIO_NUM_42
#define d2_RS GPIO_NUM_39
*/

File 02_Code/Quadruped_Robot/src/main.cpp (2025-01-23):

#include <allIncludes.h>

#define CONTROLLER
#define CONTROLLERA




singleCycle parseData(String input);

//------------------------------------------------------------------------------------------------
//angle goal values
double xAngle = 0;
double yAngle = 0;
double zAngle = 0;

double xAngleV = 0;
double yAngleV = 0;
double zAngleV = 0;


//------------------------------------------------------------------------------------------------
//angle variables
double yPreRot= 0, zPreRot = 0;
double yRot= 0, zRot = 0;


//------------------------------------------------------------------------------------------------
//PID setup for gyro
double Kp= .25, Ki=.01, Kd =0;
double angleGoal = 0;


//------------------------------------------------------------------------------------------------
//motor driver setup
#define SERVO_FREQ 50
Adafruit_PWMServoDriver pwm = Adafruit_PWMServoDriver(0x60);
Adafruit_PWMServoDriver pwm1 = Adafruit_PWMServoDriver(0x7C);


//------------------------------------------------------------------------------------------------
//location variables
Cords aCords;
Cords bCords;
Cords cCords;
Cords dCords;



Cords AcurrentPosition;
Cords BcurrentPosition;
Cords CcurrentPosition;
Cords DcurrentPosition;

//------------------------------------------------------------------------------------------------
// Motor, Leg, kinematics, interpolation set up
//float LlimitV, float HlimitV, bool directionV, float offsetV)
singleCycle activeOffsets;

motor aHipM(&pwm, aHip, 45, 135, true, &(activeOffsets.legPositions[0]));
motor aKneeM(&pwm, aKnee, 0, 180, false, &(activeOffsets.legPositions[1]));
motor aAnkleM(&pwm, aAnkle, 0, 180, true, &(activeOffsets.legPositions[2]));

motor bHipM(&pwm, bHip, 45, 135, false, &(activeOffsets.legPositions[3]));
motor bKneeM(&pwm, bKnee, 0, 180, true, &(activeOffsets.legPositions[4]));
motor bAnkleM(&pwm, bAnkle, 0, 180, false, &(activeOffsets.legPositions[5]));

motor cHipM(&pwm1, cHip, 45, 135, false, &(activeOffsets.legPositions[6]));
motor cKneeM(&pwm1, cKnee, 0, 180, false, &(activeOffsets.legPositions[7]));
motor cAnkleM(&pwm1, cAnkle, 0, 180, true, &(activeOffsets.legPositions[8]));

motor dHipM(&pwm1, dHip, 45, 135, true, &(activeOffsets.legPositions[9]));
motor dKneeM(&pwm1, dKnee, 0, 180, true, &(activeOffsets.legPositions[10]));
motor dAnkleM(&pwm1, dAnkle, 0, 180, false, &(activeOffsets.legPositions[11]));


//------------------------------------------------------------------------------------------------
//each leg object
leg Aleg(&aHipM, &aKneeM, &aAnkleM, 'A');
leg Bleg(&bHipM, &bKneeM, &bAnkleM, 'B');
leg Cleg(&cHipM, &cKneeM, &cAnkleM, 'C');
leg Dleg(&dHipM, &dKneeM, &dAnkleM, 'D');


//------------------------------------------------------------------------------------------------
//kinematic objects
kinematics AlegK(&Aleg);
kinematics BlegK(&Bleg);
kinematics ClegK(&Cleg);
kinematics DlegK(&Dleg);


//------------------------------------------------------------------------------------------------
//Ramp(interpolation) objects
rampLeg aLegR(aHip);
rampLeg bLegR(bHip);
rampLeg cLegR(cHip);
rampLeg dLegR(dHip);


//------------------------------------------------------------------------------------------------
//gyro
#define BNO055_SAMPLERATE_DELAY_MS (100)
Adafruit_BNO055 bno = Adafruit_BNO055(55, 0x28, &Wire);
sensors_event_t event;


//------------------------------------------------------------------------------------------------
//PID creation
PID yPID(&yPreRot, &yRot, &angleGoal, Kp, Ki, Kd, DIRECT);
PID zPID(&zPreRot, &zRot, &angleGoal, Kp, Ki, Kd, DIRECT);


//------------------------------------------------------------------------------------------------
//radio
PayloadStruct payload;
//RF24 radio(ce, csn)
RF24 radio(14,13);
bool newData = false;
#ifdef CONTROLLER
int oldState = 0;
const byte thisSlaveAddress[5] = {'R','x','A','A','A'};
#endif

//CE = 12, 
//CSN = 18
//sck = 13
//MISO = 17
//MOSI = 8
//------------------------------------------------------------------------------------------------
//more (different) location variables
Cords basicStand;

float cycleTime = 50;
float moveBackDistance = -50;
float moveUpDistance =-30;
//AxH,AxLR,AxFB,BxH,BxLR,BxFB,CxH,CxLR,CxFB,DxH,DxLR,DxFB
singleCycle walking0(0,0,moveBackDistance/3, // moving back
                    moveUpDistance,0,2*moveBackDistance/3, //returning to 0
                    moveUpDistance,0,2*moveBackDistance/3, //returning to 0
                    0,0,moveBackDistance/3); // moving back


singleCycle walking1(0,0,2*moveBackDistance/3, // moving back
                    moveUpDistance,0,moveBackDistance/3, //returning to 0
                    moveUpDistance,0,moveBackDistance/3,+//returning to 0
                    0,0,2*moveBackDistance/3); // moving back


singleCycle walking2(0,0,moveBackDistance, //moved back
                    0,0,0, //back at 0
                    0,0,0, //back at 0
                    0,0,moveBackDistance); //moved back


singleCycle walking3(moveUpDistance,0,2*moveBackDistance/3, //returning to 0
                    0,0,moveBackDistance/3, //moving back
                    0,0,moveBackDistance/3, //moving back
                    moveUpDistance,0,2*moveBackDistance/3); //returning to 0

singleCycle walking4(moveUpDistance,0,moveBackDistance/3, //returning to 0
                    0,0,2*moveBackDistance/3, // moving back
                    0,0,2*moveBackDistance/3, // moving back
                    moveUpDistance,0,moveBackDistance/3); //returning to 0

singleCycle walking5(0,0,0, //back at 0
                    0,0,moveBackDistance, //moved back
                    0,0,moveBackDistance, //moved back
                    0,0,0); //back at 0




//switch to size of instead of a strict n value
singleCycle walking[] = {walking0,walking1,walking2,walking3,walking4,walking5};
movementCycles walkForward(6, false,true,1000,walking);


cycleControl walkForwardCycle(&walkForward, 
                              &aLegR,&bLegR,&cLegR,&dLegR,
                              &AlegK,&BlegK,&ClegK,&DlegK,
                              &aCords,&bCords,&cCords,&dCords);


singleCycle recievedPositions;
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

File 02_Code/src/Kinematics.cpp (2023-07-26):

#include <Arduino.h>
#include <Adafruit_PWMServoDriver.h>

extern Adafruit_PWMServoDriver pwm;

#define USMIN 544  // min value given from arduino lib
#define USMAX 2400 // max value given from arduino lib

const int yHalfDis = 85;
const int zHalfDis = 125;

// constant distances
const float aLength = 95; // upper leg length more red
const float bLength = 95; // lower leg length more purple
const float Ldis = 45;

// motor definitions
const int aHip = 0;   //
const int aKnee = 1;  //
const int aAnkle = 2; //

const int bHip = 3;   //
const int bKnee = 4;  //
const int bAnkle = 5; //

const int cHip = 6;   //
const int cKnee = 7;  //
const int cAnkle = 8; //

const int dHip = 9;    //
const int dKnee = 10;  //
const int dAnkle = 11; //



const float aHipOffset = -12; // higher value = more out
const float aKneeOffset = 12; // higer value = cc
const float aAnkleOffset = 4; // higer value = larger angle

const float bHipOffset = -8; // higher value = more in
const float bKneeOffset = -0;
const float bAnkleOffset = -12;

const float cHipOffset = -5; // higher value = more in
const float cKneeOffset = -0;
const float cAnkleOffset = 5;

const float dHipOffset = -4;     // higher value = more out
const float dKneeOffset = 15;   // higer value = cc
const float dAnkleOffset = -18; // higer value = larger angle


float pytherm(float sidea, float sideb);     // returns hypotenuse c
float raddec(float rad);                     // radians to degress
float loc(float a, float b, float c);        // law of cosines, returns angle c in degress
float pythermhypt(float sidea, float sidec); // returns side b
float decrad(float deg);                     // degrees to radians




// given height, forward/back, left/right, hip motor num, knee motor num, ankle motor num, bool if on the other side.
void mainKinematics(float xH, float xFB, float xLR, int hipMotor, float xRot, float yRot, float zRot)
{
  float innerAngleKneeA, kneeAngle, outerAngleKneeB; // cah
  float zMultiplier = 1;
  float yMultiplier = 1;
  // Serial.print("this is running");

  // angle code (no idea how s rotation works so for now it is going to be ignored)
  float yRotR = decrad((yRot));
  // float yRotR = decrad(abs(yRot));
  float yAddition = yMultiplier * yHalfDis * tan(yRotR);
  if ((hipMotor == 6 || hipMotor == 3))
  {
    if (yRot < 0)
    {
      xH += yAddition;
    }
    else
    {
      xH -= yAddition;
    }
  }
  else if ((hipMotor == 0 || hipMotor == 9))
  {
    if (yRot < 0)
    {
      xH += yAddition;
    }
    else
    {
      xH -= yAddition;
    }
  }

  float zRotR = decrad((zRot));
  float zAddition = zHalfDis * tan(zRotR);
  if ((hipMotor == 0 || hipMotor == 3))
  {
    if (zRot < 0)
    {
      xFB += zAddition * zMultiplier;
    }
    else
    {
      xFB -= zAddition * zMultiplier;
    }
  }
  else if ((hipMotor == 6 || hipMotor == 9))
  {
    if (zRot < 0)
    {
      xFB += zAddition * zMultiplier;
    }
    else
    {
      xFB -= zAddition * zMultiplier;
    }
  }

  /*
  this is intended to make the kinematic system into a single function that works for all legs
  it could be done with fewer inputs, however this is going to make it was easier for me
  */

  if(xH >= 190){
    xH = 190;
  }else if (xH<= 20){
    xH = 20;
  }

  if (xFB >= 50){
    xFB = 50;
  }else if(xFB <=-70){
    xFB = -70;
  }

  if(xLR >= 50){
    xLR = 25;
  }else if(xLR <= -25){
    xLR = -25;
  }

  // hip angle


  float innerLegLength = pytherm(xH, Ldis + xLR);
  // now must solve for 1st purple angle
  // using cos, a/h
  // now for the second triangle of the first part
  float modLegL = pythermhypt(Ldis, innerLegLength); // most outer triangle

  float innerAngleA = acos(xH / innerLegLength); // adj / hyp

  innerAngleA = raddec(innerAngleA);

  // now must solve for the 2nd purple angle
  float innerAngleB = acos(Ldis / innerLegLength); // adjacent and hyp cah soh
  innerAngleB = raddec(innerAngleB);
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

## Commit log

2023-02-27 First PCB revision
2023-03-01 Added function to set stepper motor offsets
    New temp function that allows the servo offsets to be set in a more precise manner, if manual, however with the read out the gyro values it makes it much easier to ensure that the bot is level
2023-03-14 Modifications for PCB
    Changed I2C pins to reflect the PCB
    Changed servo offsets to reflect the higher voltage of the motors
2023-03-16 walking and separate files
    First walking without active stabilization (no gyro in use yet), separated kinematics and other functions into a separate file.
2023-03-16 Cover For Gyro
    Cover plate for gyroscope as well as the updated assembly for the body section
    [bno055cover.FCStd, bodyassembly.FCStd]
2023-03-23 Better walking + gyro enable/pid
    The gyroscope can be enabled or disabled with a single variable, the gyro also uses a pid loop to reduce the amount of oscillation that occurs when the bot tries to remain level (untested pid, values, but code is implemented)
    Walking no longer holds the microcontroller in its while loop, through the use of states which then update the ramp walking values
    [main.cpp]
2023-03-23 Added PID library
    Added PID library to build file, currently in use for the gyroscope
2023-04-18 Finished Walking
    Robot is now able to walk, walking file holds the cycles and states, currently side up in a 2 leg off the ground config. Gyro is currently disabled, but gait works with it enabled
2023-07-26 Added V7 of the Cad
    Minus the legs, those are the same as v6 and hence will need to be moved into this version at a later date
    [BatteryHolder.FCStd, Mainboard_Holder.FCStd, Rod.FCStd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]
2023-07-26 Create V5 Cad Folder
2023-07-26 Moved V5 Files into V5 Location
    [2servohorn.FCStd, 4servohorn.FCStd, 608Zballbearing.FCStd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]
2023-07-26 Moved Old PCB to V5
    [2servohorn.FCStd, 4servohorn.FCStd, 608Zballbearing.FCStd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]
2023-08-01 Adding Changing to V7
    Added a function called all 90s, has all motors at 90. Started to convert kinematic model to V7
    [BatteryHolder.FCStd]
2023-08-02 Fixing Code for V7
    Fixed the write microseconds to work properly, set offsets of motors to match my current design. V7 is now capable of movement
    [Kinematics.cpp, main.cpp]
2023-08-03 Intial Gyro V7
    Tested gyro for V7 and made the kinematic model work with positive xFB (forward) values
2023-08-08 Switching to a class system
2023-08-11 Finished Transition to Class control
    Finished Leg class
    changed code to use class
    made walking more efficient, moving in 2 directions at the same time is now possible
    Removed turning code in prep for revamp
2023-08-22 fixed some issues with leg class
    [Kinematics.cpp, main.cpp]
2023-08-27 Added temp sit position
    [assemv7.FCStd]
2023-09-06 Code to test NRF24
    Currently NRF24's appear to be working but no data is sent inbetween nodes
2023-09-08 Fixed RX test code
    [main.cpp]
2023-09-08 RX test code fixed
    [main.cpp]
2023-09-17 Changed Project Structure
    Added new cpp files to reduce the size of main, Variables.cpp includes all global variables. Modes includes the functions that were in the switch statement
2023-09-21 Reorganized files
    Added description of functions, hopefully resolved gyro issue by changing how it is treated when active and not active
    [Kinematics.cpp, Modes.cpp, main.cpp]
2023-09-30 Fixed compiling issue
    populateStructs had the wrong function definition in externFunctions.h
    [Kinematics.cpp]
2023-10-01 Switching how motors, and other work
    Uses a unified setup to control angles of motors (50 degrees on all motors of the same position will all look the same). Switch to a multistage class system to handle motors>legs>Ikinematics>ramps. S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
2023-10-08 Added PCBs
    [BatteryHolder.FCStd, PCB_ServoDriverV2.json, ServoDriverV2.json]
2023-10-20 pcb update code
2023-10-30 Fixed Gyro, OTA, Telnet
    Added proper support for gyroscope (added to kinematic model). OTA updates were also added to allow for easier development. Telnet was also added for a replacement for serial over wireless
    [main.cpp]
2023-11-11 Code Reorganization + gyro
2024-01-18 Fixed Code for V8
    [Modes.cpp, main.cpp]
2024-01-18 Added V8 CAD
    [608Zballbearing.FCStd, InnerUpperLeg.FCStd, LowerLeg.FCStd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]
2024-01-18 Added new PCB revisions
    [PCB_ServoDriverV2.json, ServoDriverV2.json]
2024-04-26 Slight cad change
    [InnerUpperLeg.FCStd, Rod.FCStd, assembly.FCStd]
2024-08-19 Lower Lewg Fix + new movement method
    Moved the coupler bar to the outside of the leg. Started switch to new motion system.
    [LowerLeg.FCStd, Outer1.FCStd, Outer2.FCStd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]
2024-08-20 Old walking working + offset tool
    Fixed old walking prior to switch to new method, added tool to find motor offsets without reuploading code multiple times.
    [main.cpp, motion.cpp, motorOffset.py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]
2024-08-26 Fixed Waling + readded gyro
    [main.cpp, motorOffsets.h]
2024-09-17 Cad update
    [assembly.FCStd, buckandswitch.FCStd, gyro holder.FCStd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]
2025-01-23 Minor CAD Changes
    [mainboardHolder.FCStd]
2025-07-30 Removed display code
    [608Zballbearing.FCStd, LowerLeg.FCStd, RealOuterUpperLeg.FCStd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]
2025-10-24 CAD changes for V10, IK rework
    [CAN_SERVO_PCB_HOLDER.FCStd, INNER_PLATE.FCStd, KNEE_MOTOR_HOLDER.FCStd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]
